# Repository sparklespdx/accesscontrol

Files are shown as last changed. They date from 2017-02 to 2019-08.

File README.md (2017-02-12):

accesscontrol
=============

Access Control System Software

This is the software for the access control system created for [Ctrl-H](http://ctrlh.org/),
a hackerspace in Portland, OR.  

ARCHIVE NOTES BELOW THIS POINT
------------------------------
Schematics will be available at some point.  Check out the [Instructable](http://www.instructables.com/id/RFID-Access-Control-System/).

Uses the Raspberry Pi GPIO module from https://pypi.python.org/pypi/RPi.GPIO/ .

contact rmiller @ duskglow dot com with questions.

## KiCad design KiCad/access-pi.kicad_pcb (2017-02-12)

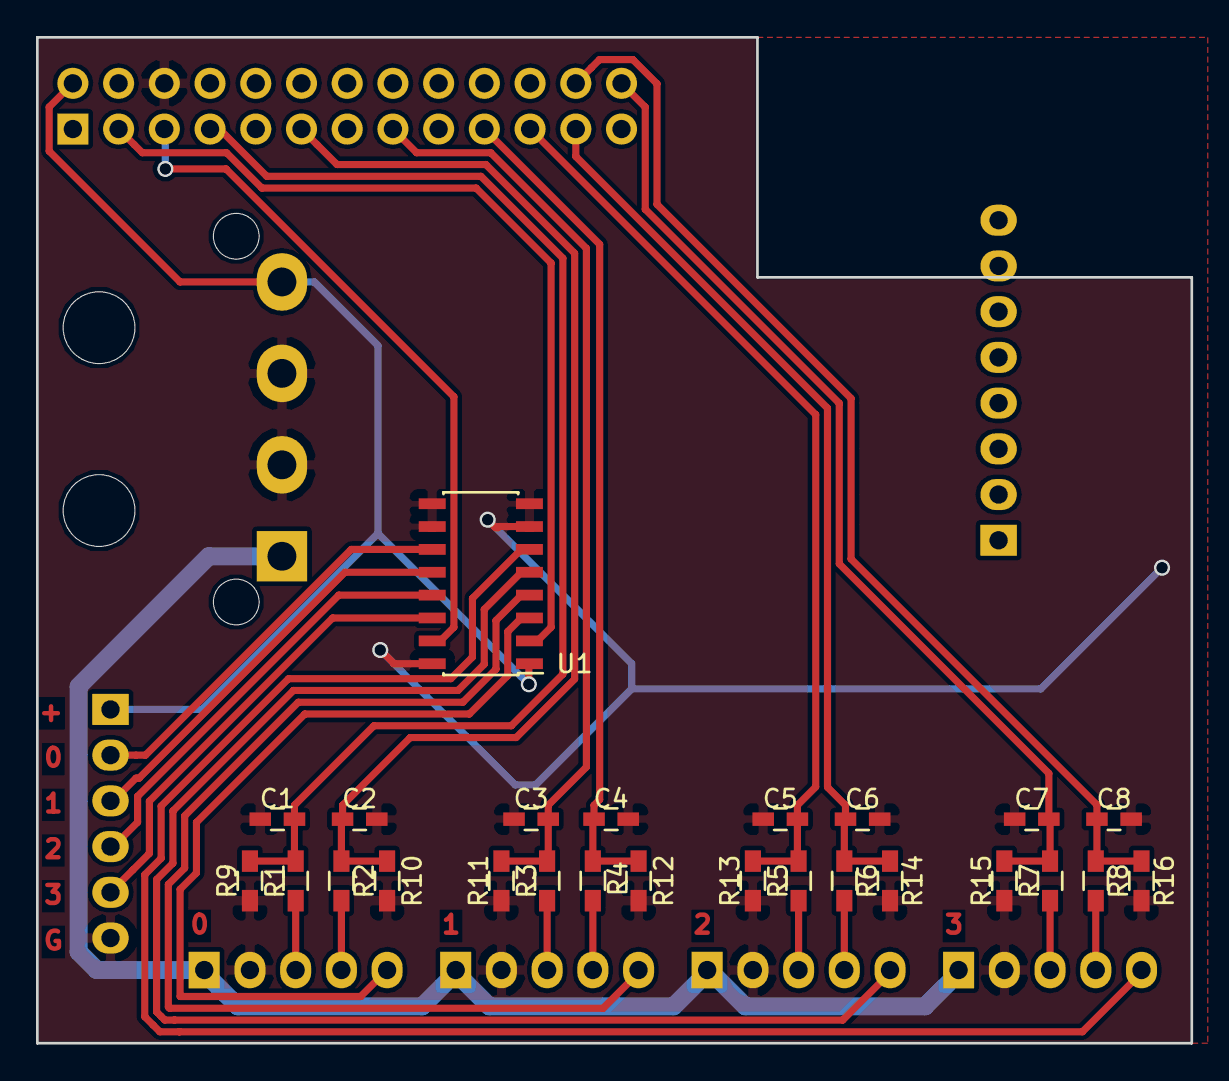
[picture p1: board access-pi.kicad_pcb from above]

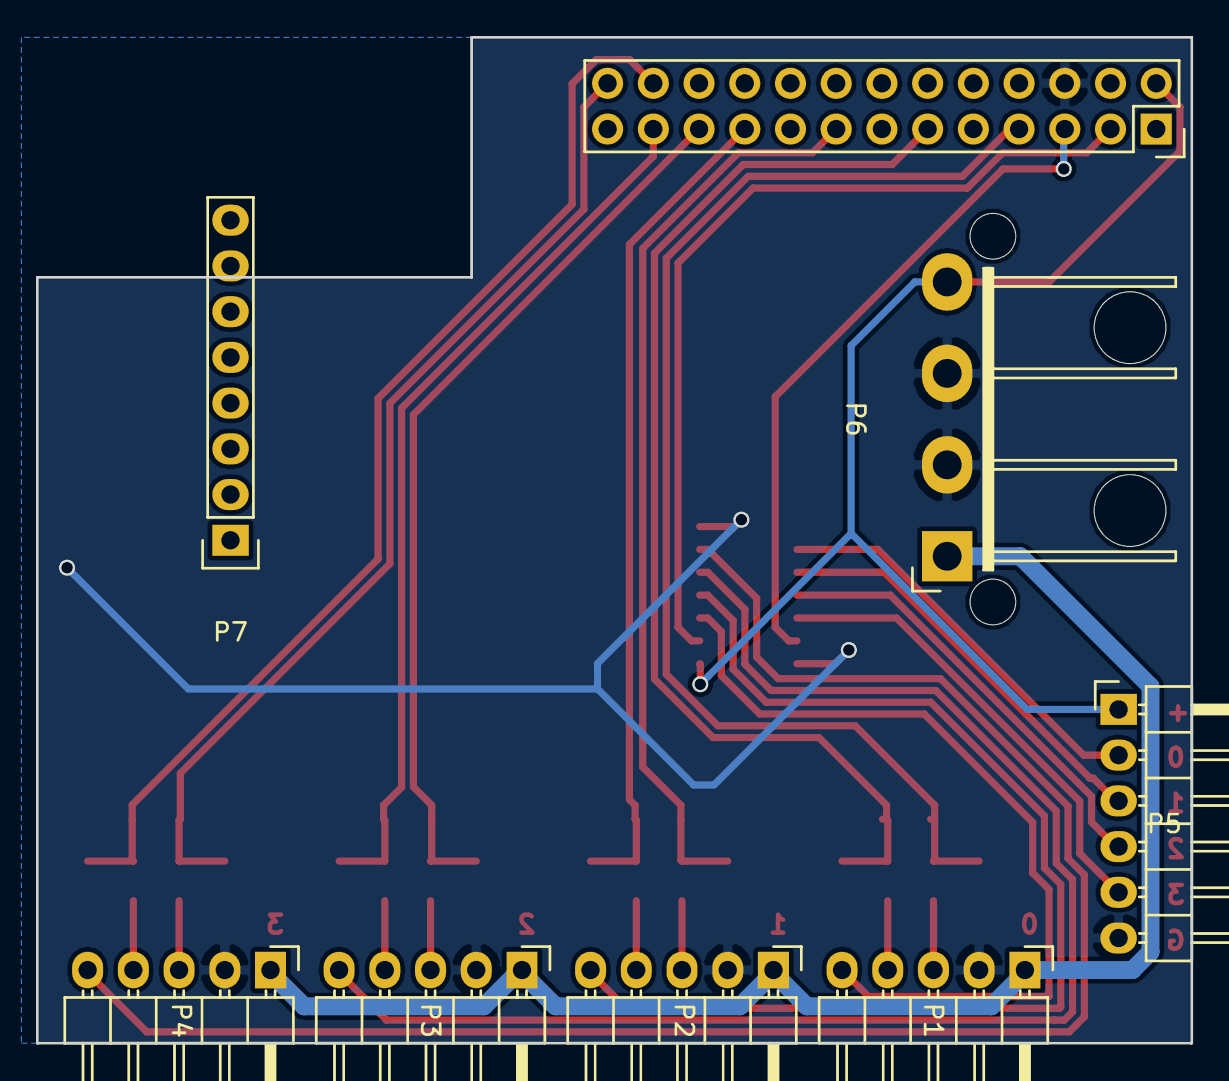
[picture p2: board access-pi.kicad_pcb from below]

Board: 2 copper layers, 64.1 x 55.9 mm, 33 parts (8 on the bottom side), 29 nets.

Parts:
C1, C2, C3, C4, C5, C6, C7, C8: 1n; C_0603_HandSoldering
P1, P2, P3, P4: CONN_01X05; Pin_Header_Angled_1x05
P5: CONN_01X06; Pin_Header_Angled_1x06
P6: Molex_8981; Molex_15-24-4441
P7: CONN_01X08; Pin_Header_Straight_1x08
R1, R2, R3, R4, R5, R6, R7, R8: 12k7; R_0603_HandSoldering
R9, R10, R11, R12, R13, R14, R15, R16: 22k; R_0603_HandSoldering
RPi1: RASPBERRY_IO; Socket_Strip_Straight_2x13
U1: TPIC2810; SOIC-16_3.9x9.9mm_Pitch1.27mm

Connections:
+5V: P5.1, P6.4, RPi1.2, U1.1
+12V: P1.1, P2.1, P3.1, P4.1, P6.1
/R0_D0: P1.3, R1.2
/R0_D1: P1.4, R2.2
/R0_LED: P1.5, U1.3
/R1_D0: P2.3, R3.2
/R1_D1: P2.4, R4.2
/R1_LED: P2.5, U1.4
/R2_D0: P3.3, R5.2
/R2_D1: P3.4, R6.2
/R2_LED: P3.5, U1.5
/R3_D0: P4.3, R7.2
/R3_D1: P4.4, R8.2
/R3_LED: P4.5, U1.6
GND: C1.1, C2.1, C3.1, C4.1, C5.1, C6.1, C7.1, C8.1, P1.2, P2.2, P3.2, P4.2, P5.6, P6.2, P6.3, R9.1, R10.1, R11.1, R12.1, R13.1, R14.1, R15.1, R16.1, RPi1.6, U1.7, U1.8, U1.9, U1.10, U1.16
unnamed: C1.2, R1.1, R9.2, RPi1.7
unnamed: C2.2, R2.1, R10.2, RPi1.11
unnamed: C3.2, R3.1, R11.2, RPi1.15
unnamed: C4.2, R4.1, R12.2, RPi1.19
unnamed: C5.2, R5.1, R13.2, RPi1.21
unnamed: C6.2, R6.1, R14.2, RPi1.23
unnamed: C7.2, R7.1, R15.2, RPi1.26
unnamed: C8.2, R8.1, R16.2, RPi1.24
unnamed: P5.2, U1.11
unnamed: P5.3, U1.12
unnamed: P5.4, U1.13
unnamed: P5.5, U1.14
unnamed: RPi1.3, U1.2
unnamed: RPi1.5, U1.15

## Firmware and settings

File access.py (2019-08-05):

#!/usr/bin/python
#
# vim: et ai sw=4

import json
import smtplib
import threading

from RPi import GPIO
import sys
import time
import signal
import syslog
import socket

conf_dir = "./conf/"


class Config(object):

    def __init__(self):
        self.configs = {"i2c":{}}

    def add_config_file(self, filename):
        try:
            with open(conf_dir + filename + ".json") as file_handle:
                try:
                    config = json.load(file_handle)
                    if config > 0:
                        self.configs[filename] = config
                except ValueError:
                    logger.report("%s unable to load %s file.  Please check for syntax errors." %
                                (socket.gethostname(), filename))
        except IOError:
            self.configs[filename] = {} # FIXME figure out how to revert on a bad read

    def __getitem__(self, item):
        for config in self.configs.values():
            val = config.get(item)
            if val is not None:
                return val
        return None

    def __getattr__(self, item):
        if item in self.configs:
            return self.configs[item]
        raise AttributeError()


class Output(object):
    # GPIOs and I2C shift-register outputs

    def __init__(self, address, unlock_value, open_delay):
        if type(address) is int:
            GPIO.setup(address, GPIO.OUT)
        self.address = address
        self.unlock_value = unlock_value
        self.open_delay = open_delay
        self.deactivate()

    def set_out(self, go_active=False):
        new_value = go_active ^ self.unlock_value ^ 1
        if type(self.address) is int:
            GPIO.output(self.address, new_value)
        elif type(self.address) is unicode:
            (addr, bit) = [int(x, 16) for x in self.address.split('.')]
            if not config.i2c.get(addr):
                config.i2c[addr] = 0
            if new_value:
                config.i2c[addr] |= 1 << bit
            else:
                config.i2c[addr] &= 1 << bit ^ 0xFF
            bus.write_byte_data(addr, 0x44, config.i2c[addr])   # TPIC2810 compatible
        else:
            logger.debug("gpio is unknown type: %s" % type(self.address))

    def deactivate(self):
        self.set_out(False)

    def activate(self):
        self.set_out(True)

    def timed_activation(self):
        self.activate()
        time.sleep(self.open_delay)
        self.deactivate()


class CardReader(object):
    # when scan happens, validate, check for authorization, and fire events if successful

    def __init__(self, reader_config):
        if reader_config["name"] == "<door_name>":
            return None
        if reader_config["is_locker"]:
            self.is_locker = True
            self.lockers = []
            for locker in reader_config["doors"]:
                self.lockers.append(Locker(locker, self))
        else:
            self.is_locker = False
            self.door = Door(reader_config["doors"][0], self)
            self.event_mode_timeout = reader_config.get("event_mode_timeout", None)
        if reader_config.get("led"):
            green_value = 1
            if type(reader_config.get("led_green_value")) == int:
                green_value = reader_config["led_green_value"]
            self.led = Output(reader_config["led"], green_value, 1)
        self.name = reader_config["name"]
        self.stream = ""
        self.timer = None
        self.unlocked = False
        self.data0 = reader_config["data0"]
        self.data1 = reader_config["data1"]
        self.permissions = reader_config["permissions"]
        self.permissions.append(self.name)
        GPIO.setup(self.data0, GPIO.IN)
        GPIO.setup(self.data1, GPIO.IN)
        GPIO.add_event_detect(self.data0, GPIO.FALLING,
                              callback=self.data_pulse)
        GPIO.add_event_detect(self.data1, GPIO.FALLING,
                              callback=self.data_pulse)

    def find_locker(self, name):
        for locker in self.lockers:
            if locker.name == name:
                return locker
        return None

    def data_pulse(self, channel):
        if channel == self.data0:
            self.stream += "0"
        elif channel == self.data1:
            self.stream += "1"
        self.kick_timer()

    def kick_timer(self):
        if self.timer is None:
            self.timer = threading.Timer(0.2, self.wiegand_stream_done)
            self.timer.start()

    def wiegand_stream_done(self):
        if self.stream == "":
            return
        bstr = self.stream
        self.stream = ""
        self.timer = None

        # verify length and split into components
        if len(bstr) != 26:
            logger.debug("%s received bad string length: %i\n:%s:" %
                    (self.name, len(bstr), bstr))
            return False
        lparity = int(bstr[0])
        facility = str(int(bstr[1:9], 2))
        user_id = str(int(bstr[9:25], 2))
        rparity = int(bstr[25])
        logger.debug("%s %s is: %i %s %s %i" %
                (self.name, bstr, lparity, facility, user_id, rparity))

        # verify parity
        calculated_lparity = 0
        calculated_rparity = 1
        for iter in range(0, 12):
            calculated_lparity ^= int(bstr[iter + 1])
            calculated_rparity ^= int(bstr[iter + 13])
        if (calculated_lparity != lparity or calculated_rparity != rparity):
            logger.debug("%s received string with bad parity!" % self.name)
            return False

        card_id = "%08x" % int(bstr, 2)
        logger.debug("%s successfully decoded %s facility=%s user=%s" %
              (self.name, card_id, facility, user_id))

        # lookup card
        user = (config.users.get("%s,%s" % (facility, user_id)) or
                config.users.get(card_id) or
                config.users.get(card_id.upper()) or
                config.users.get(user_id))
        if (user is None):
            logger.debug("couldn't find user")
            return self.reject_card()
        if (self.is_locker and user.get("locker")):
            found_locker = self.find_locker(user["locker"])
            if found_locker is None:
                return logger.debug("%s does not have a locker" % user["name"])
            return found_locker.open_locker(user)
        else:
            # event mode unlock
            if "event host" in user["permissions"] and self.event_mode_timeout is not None:
                if self.door.last_opened > time.time() - self.event_mode_timeout or self.door.unlocked:
                    return self.door.toggle_lock(user)
            # normal user auth
            for my_permission in self.permissions:
                if my_permission == "*" or my_permission in user["permissions"]:
                    return self.door.open_door(user)
        logger.debug("%s is not authorized for %s" %
                (user["name"], self.name))
        self.reject_card()

    def reject_card(self):
        logger.report("A card was presented at %s %s and access was denied" %
                    (socket.gethostname(), self.name))
        return False


class Door(object):
    # when associate reader sends event, open

    def __init__(self, door_config, reader):
        self.reader = reader
        self.name = door_config["name"]
        self.latch = Output(door_config["latch_gpio"], door_config["unlock_value"], door_config["open_delay"])
        self.open_delay = door_config["open_delay"]
        self.unlocked = False
        self.last_opened = None

    def toggle_lock(self, user):
        public_name = logger.public_name(user)
        self.unlocked ^= True
        if self.unlocked:
            logger.report("%s %s unlocked by %s" % (socket.gethostname(), self.name, public_name))
            self.latch.activate()
            self.reader.led.activate()
        else:
            logger.report("%s %s locked by %s" % (socket.gethostname(), self.name, public_name))
            self.latch.deactivate()
            self.reader.led.deactivate()

    def open_door(self, user):
        now = time.time()
        public_name = logger.public_name(user)
        if self.unlocked:
            logger.report("%s found %s %s is already unlocked" %
                        (public_name, socket.gethostname(), self.name))
        else:
            logger.report("%s has opened %s %s" %
                        (public_name, socket.gethostname(), self.name))
            self.last_opened = now
            self.latch.activate()
            time.sleep(self.open_delay)
            if not self.unlocked:
                self.latch.deactivate()

class Locker(object):
    # when associated reader sends read event, open correct user's locker

    def __init__(self, locker_config, reader):
        self.name = locker_config["name"]
        self.reader = reader
        self.latch = Output(locker_config["latch_gpio"], locker_config["unlock_value"], locker_config["open_delay"])
        #self.unlocked = False

    def open_locker(self, user):
        logger.report("%s has opened %s locker %s" %
                (logger.public_name(user), socket.gethostname(), self.name))
        self.latch.timed_activation()


class AdvancedRule(object):
    # can subscribe to any events (signals, card reads, successful card authorizations,
    # time(?), door open/close.
    # has access to all system information
    # can alter the structure of readers, doors, configs, rules.
    # maybe we just initialize these with a global function and let it do whatever...
    pass


class Logger(object):

    def __init__(self, config):
        self.config = config
        self.debug_mode = self.config["debug_mode"] or False

    def debug(self, message):
        if self.debug_mode:
            print message
            sys.stdout.flush()

    def toggle_debug(self, sig, frame):
        if self.debug_mode:
            self.debug("Disabling debug messages")
        self.debug_mode ^= True
        if self.debug_mode:
            self.debug("Enabling debug messages")

    def send_email(self, subject, body=""):
        try:
            emailfrom = self.config["emailfrom"]
            to = self.config["emailto"]
            smtpserver = smtplib.SMTP(self.config["emailserver"], self.config["emailport"])
            smtpserver.ehlo()
            header = "To: %s\nFrom: %s\nSubject: %s\n" % (to, emailfrom, subject)
            msg = "%s\n%s\n\n" % (header, body)
            smtpserver.sendmail(emailfrom, to, msg)
            smtpserver.close()
        except smtplib.SMTPException:
            # couldn't send.
            pass

    def public_name(self, user):
        if self.config["abbreviate_last_name"]:
            first, last = user["name"].split(" ")
            return "%s %s." % (first, last[0])
        else:
            return user["name"]

    def report(self, subject):
        syslog.syslog(subject)
        self.debug(subject)
        if self.config["emailserver"]:
            # TODO: does send_email need to be a function
            t = threading.Thread(target=self.send_email, args=[subject])
            t.start()


def initialize(config, logger):
    GPIO.setmode(GPIO.BCM)
    syslog.openlog("accesscontrol", syslog.LOG_PID, syslog.LOG_AUTH)
    logger.debug("Initializing")
    config.add_config_file("users")
    setup_readers()
    # Catch some exit signals
    signal.signal(signal.SIGINT, cleanup)   # Ctrl-C
    signal.signal(signal.SIGTERM, cleanup)  # killall python
    # These signals will reload users
    signal.signal(signal.SIGHUP, rehash)    # killall -HUP python
    signal.signal(signal.SIGUSR2, rehash)   # killall -USR2 python
    # This one will toggle debug messages
    signal.signal(signal.SIGWINCH, logger.toggle_debug)  # killall -WINCH python
    logger.report("%s access control is online" % socket.gethostname())

def rehash(signal=None, b=None):
    logger.report("%s reloading access list" % socket.gethostname())
    config.add_config_file("users")

def setup_readers():
    for reader in iter(config["readers"]):
        CardReader(reader)

def cleanup(a=None, b=None):
    logger.report("%s access control is going offline" % socket.gethostname())
    GPIO.setwarnings(False)
    GPIO.cleanup()
    sys.exit(0)


config = Config()
config.add_config_file("config")
logger = Logger(config)

bus = None
if type(config["i2c_bus"]) == int:
    from smbus import SMBus
    bus = SMBus(config["i2c_bus"])

if __name__ == '__main__':
    initialize(config, logger)

    while True:
        # The main thread should open a command socket or something
        time.sleep(1000)

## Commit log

2015-02-16 Flushing old Arduino Yun code.
2015-02-16 Freshening for the latest Raspberry Pi goodness
2015-02-17 started redesigning configs simplified objects instead of globals
    [access.py]
2015-05-08 Try not to crash when rehashing with bad user file
    [access.py]
2015-05-12 More work on objects, tested good but sloppy
    This is working with the 4-door reader hardware but it needs
    serious cleanup and review.
    [access.py]
2015-05-14 Fixed confusing local use of global object name
    [access.py]
2016-02-08 Flush prints so debug.log isn't blocked
2017-02-12 Added board design files for old Raspberry Pi
    [access-pi-B.Cu.gbl, access-pi-B.Mask.gbs, access-pi-B.Paste.gbp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]
2019-06-05 Refactor for event mode master key
    Looks like I replaced some tabs with spaces too
    [access.py]
2019-06-06 Match our test bed
2019-06-06 Configure if event mode even works
    Unless "event_mode_timeout" is configured on a reader, event mode will
    not work.
    [access.py]
2019-08-05 fixed toggle_lock() logger message typo
    [access.py]
2019-08-05 Make output to green LED configurable
2019-08-05 Fix classless call typo
    [access.py]
2019-08-05 Make the i2c bus number configurable
